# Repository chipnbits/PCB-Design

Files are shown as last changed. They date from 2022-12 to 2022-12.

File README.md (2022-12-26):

# PCB-Design

### Files:
- PCB Course Certificate : A certificate showing completion of 30 hour PCB design course
- overview.png : A visual overview of the project and results
- pcbDesign.kicad_pcb : PCB layout file in KiCAD
- signalGeneratorGerber.zip : Gerber files

### Description:

A signal generator PCB design project performed as part of a 30 hour course through the UBC PHAS Elab, Fall 2022.  A 15V DC signal is passed through a voltage regulator to produce 5V DC.  The 5V is passed through a 5V -> -5V converter to power the rails of an op-amp that can control output signal amplitude.  5V powers a 100kHz Timer/Oscillator that produces a squarewave signal that can be tuned in combination with the potentiometers and the op-amp.  Tuned signal can be read from a through-hole test port.

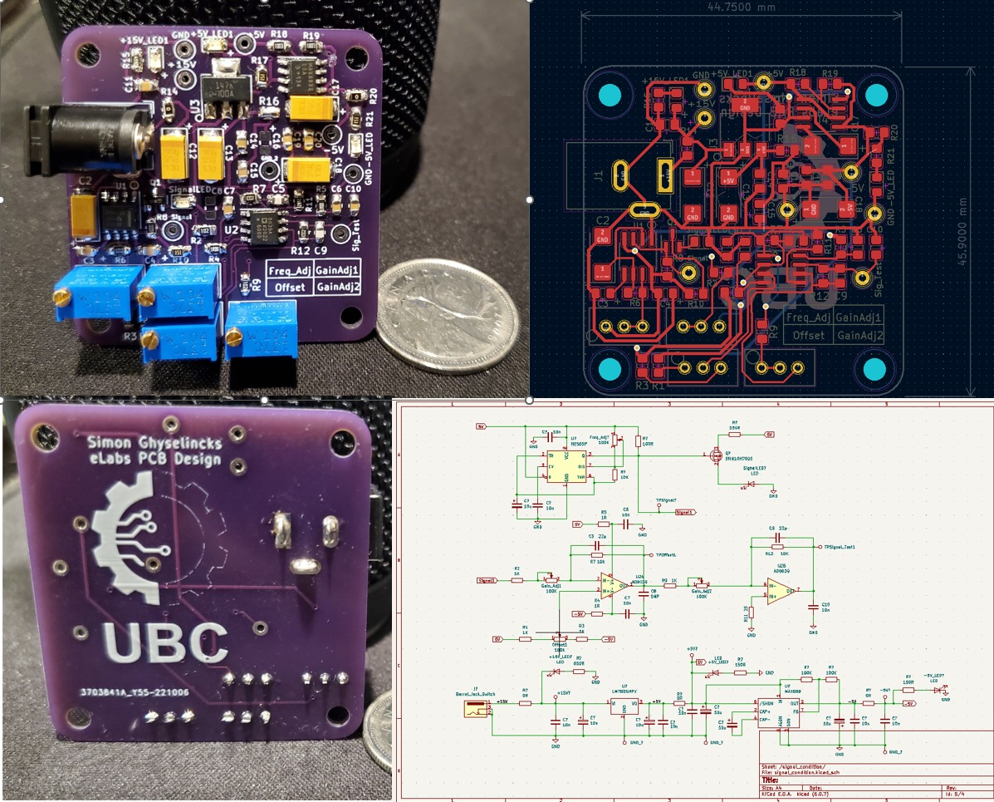
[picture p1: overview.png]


Project phases included:

#### Design
- Creating a schematic in EDA software (KiCad), including additions to the parts library.
- Creating custom component footprints to match manufacturer specifications.
- Review of good design priciples for PCB circuit layout.
- Manual layout of circuit onto a two-layer PCB, design rules specifications, variable width traces.
- Custom silk screen layering, sizing, and drill holes for ease of assembly.
- Gerber file production and PCB ordering.

#### Assembly
- Manual soldering of surface mount components with a Sainsmart TS-100 Iron.
- Testing and validation with digital oscilloscope and multimeter.
- Use of one jumper wire to correct a connection issue not flagged properly by EDA.

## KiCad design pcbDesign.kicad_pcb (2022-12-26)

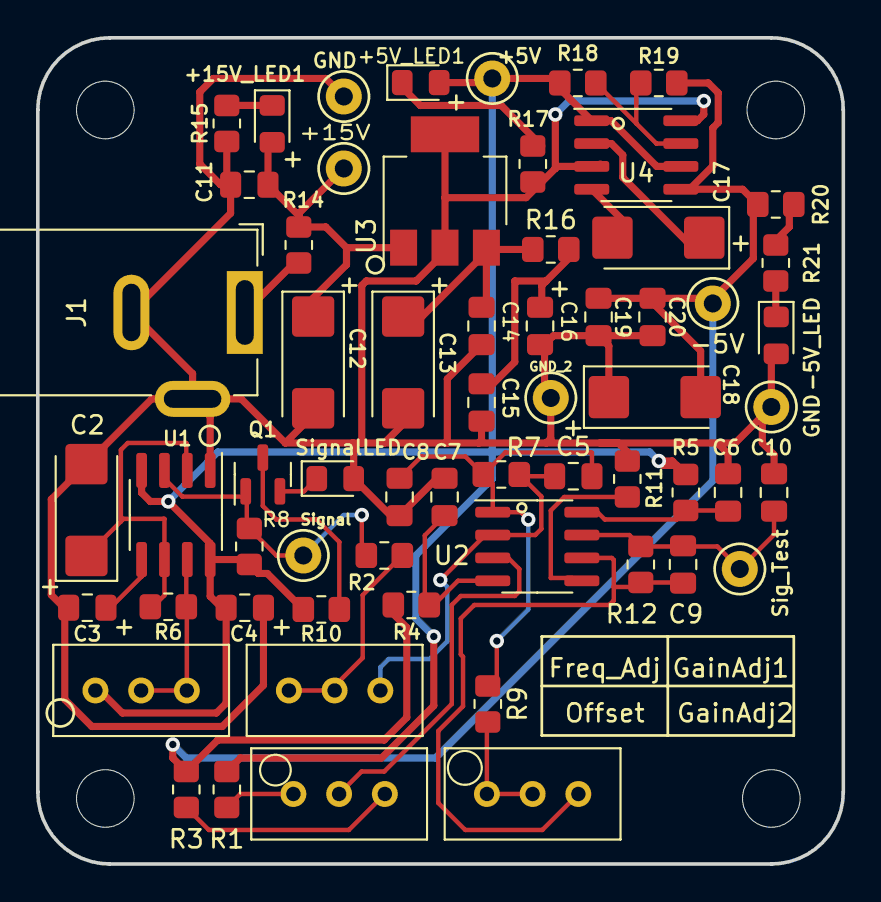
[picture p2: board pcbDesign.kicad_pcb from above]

Board: 2 copper layers, 44.7 x 45.9 mm, 65 parts (0 on the bottom side), 30 nets.

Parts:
+5V, +15V: TestPoint; TestPoint_Keystone_5000-5004_Miniature
+5V_LED1, +15V_LED1: LED
-5V: TestPoint; TestPoint_Keystone_5000-5004_Miniature
-5V_LED: LED
C2, C12, C13, C17, C18: 10u; polar capacitor
C3, C4, C6, C7, C10, C11, C14, C15, C19, C20: 10n; C 0805
C5, C9: 22p; C 0805
C8: DNP; C 0805
C16: 10u; C 0805
Freq_Adj: 100K; Potentiometer_Bourns_3296W_Vertical
GND: TestPoint; TestPoint_Keystone_5000-5004_Miniature
GND#2: TestPoint; TestPoint_Keystone_5000-5004_Miniature
GND_2: TestPoint; TestPoint_Keystone_5000-5004_Miniature
GainAdj1, GainAdj2: 100K; Potentiometer_Bourns_3296W_Vertical
H1: MountingHole; MountingHole_3.2mm_M3
H2, H3, H4: MountingHole; MountingHole_3.2mm_M3_DIN965
J1: Barrel_Jack_Switch; BarrelJack_GCT_DCJ200-10-A_Horizontal
Offset: 100K; Potentiometer_Bourns_3296W_Vertical
Q1: DMN10H700S; SOT-23
R1, R2, R3, R9: 1K; R_0805_2012Metric_Pad1.20x1.40mm_HandSolder
R4, R5: 1R; R_0805_2012Metric_Pad1.20x1.40mm_HandSolder
R6, R7, R12: 10K; R_0805_2012Metric_Pad1.20x1.40mm_HandSolder
R8: 100R; R_0805_2012Metric_Pad1.20x1.40mm_HandSolder
R10, R17, R21: 150R; R_0805_2012Metric_Pad1.20x1.40mm_HandSolder
R11: 25; R_0805_2012Metric_Pad1.20x1.40mm_HandSolder
R14, R16, R20: 0R; R_0805_2012Metric_Pad1.20x1.40mm_HandSolder
R15: 650R; R_0805_2012Metric_Pad1.20x1.40mm_HandSolder
R18, R19: 100K; R_0805_2012Metric_Pad1.20x1.40mm_HandSolder
Sig_Test: TestPoint; TestPoint_Keystone_5000-5004_Miniature
Signal: TestPoint; TestPoint_Keystone_5000-5004_Miniature
SignalLED: LED
U1: NE555P; NE555DR
U2: AD8039; SOIC-8_3.9x4.9mm_P1.27mm
U3: LM7805MPX; LM7805
U4: MAX889; SOIC-8_3.9x4.9mm_P1.27mm

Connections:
5V: +5V.1, +5V_LED1.2 (A), C4.2, C15.1, C16.1, Freq_Adj.1, R1.1, R5.1, R8.1, R10.2, R16.2, R18.1, U1.4 (R), U1.8 (VCC), U4.1 (IN), U4.6 (/SHDN)
-5V: -5V.1, C18.2, C19.1, C20.1, R3.2, R4.1, R19.2, R20.1, R20.2, R21.1, U4.5 (OUT)
/PS/+5V: C13.1, C14.1, R16.1, U3.3 (VO)
/PS/+15V: J1.1, R14.1
GND: -5V_LED.2 (A), C2.2, C3.2, C4.1, C6.2, C7.2, C8.1, C10.1, C11.2, C12.2, C13.2, C14.2, C15.2, C16.2, C18.1, C19.2, C20.2, GND.1, GND#2.1, GND_2.1, J1.2, J1.3, R11.1, R15.2, R17.2, SignalLED.2 (A), U1.1 (GND), U3.2 (GND), U4.3 (GDN), U4.8 (AGDN)
unnamed: +5V_LED1.1 (K), R17.1
unnamed: +15V.1, +15V_LED1.2 (A), C11.1, C12.1, R14.2, U3.1 (VI)
unnamed: +15V_LED1.1 (K), R15.1
unnamed: -5V_LED.1 (K), R21.2
unnamed: C2.1, R6.2, U1.2 (TR), U1.6 (THR)
unnamed: C3.1, U1.5 (CV)
unnamed: C5.1, GainAdj1.3, R7.1, U2.2 (IN-)
unnamed: C5.2, C8.2, R7.2, R9.1, U2.1 (OUT)
unnamed: C6.1, R5.2, U2.8 (V+)
unnamed: C7.1, R4.2, U2.4 (V-)
unnamed: C9.1, GainAdj2.3, R12.1, U2.6 (IN-)
unnamed: C9.2, C10.2, R12.2, Sig_Test.1, U2.7 (OUT)
unnamed: C17.1, U4.2 (CAP+)
unnamed: C17.2, U4.4 (CAP-)
unnamed: Freq_Adj.2, Freq_Adj.3, R6.1, U1.7 (DIS)
unnamed: GainAdj1.1, GainAdj1.2, R2.2
unnamed: GainAdj2.1, GainAdj2.2, R9.2
unnamed: Offset.1, R1.2
unnamed: Offset.2, U2.3 (IN+)
unnamed: Offset.3, R3.1
unnamed: Q1.2 (S), SignalLED.1 (K)
unnamed: Q1.3 (D), R10.1
unnamed: R11.2, U2.5 (IN+)
unnamed: R18.2, R19.1, U4.7 (FB)
Signal1: Q1.1 (G), R2.1, R8.2, Signal.1, U1.3 (Q)
